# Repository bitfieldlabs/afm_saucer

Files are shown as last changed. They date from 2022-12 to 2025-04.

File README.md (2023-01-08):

# :flying_saucer: An RGB Attack from Mars Pinball Saucer PCB Replacement
As the title suggests this is drop in replacement for your Attack from Mars pinball saucer PCB. The large one.

No additional components or connections required!

As a bonus you get nice RGB colors!

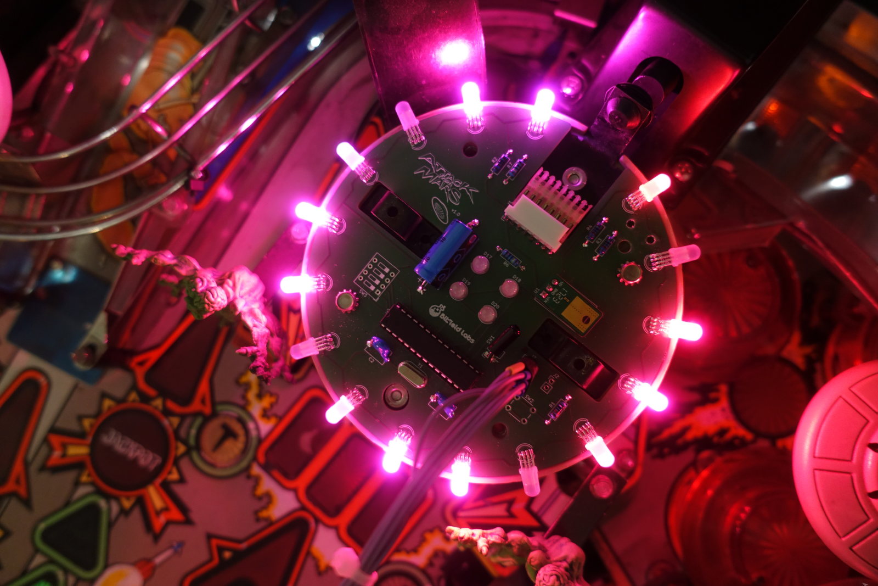
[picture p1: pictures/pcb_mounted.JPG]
mounted pcb


See a video of the saucer in action: https://vimeo.com/777834938

## :jigsaw: Required Components
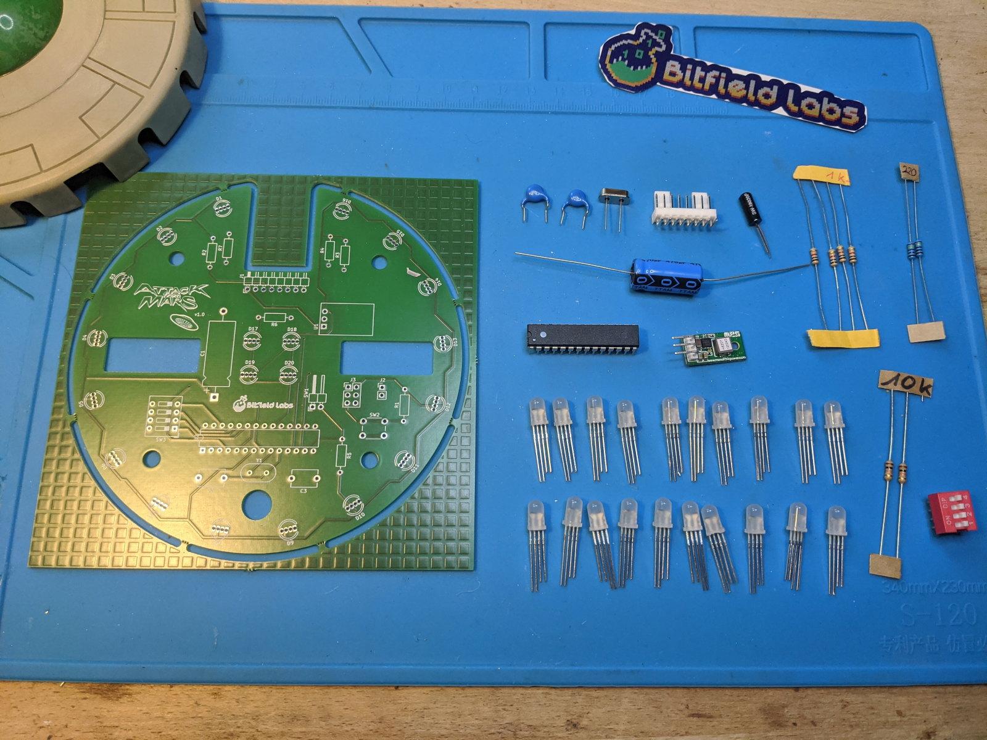
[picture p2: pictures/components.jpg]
components


The BOM is [here](https://github.com/bitfieldlabs/afm_saucer/blob/master/afm_saucer_pcb/afm_saucer/afm_saucer_bom.csv).
 
## :page_facing_up: Instructions
Some instructions can be found in the [doc folder](https://github.com/bitfieldlabs/afm_saucer/tree/master/doc).

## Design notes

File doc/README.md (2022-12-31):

## Assembly instructions
### Notes
It's easiest to start with the smalles (lowest profile) components and work the way up to the largest ones.

* *Note 1* Mind the polarity for the large capacitor C1!
* *Note 2* Mind the polarity for the Atmega chip U2!
* *Note 3* Mind the polarity for the LEDS! The flat side (-) is marked on the PCB. It's the connection with the square solder pad. It matches the LED's long legs.
* *Note 4* The legs of the 5V regulator (U1) must be bent straight in order to solder it flat to the PCB (see images). The VO (voltage out) pin must be connected to the upper solder pad, where U1 is marked. VI (voltage in) points toward the middle of the PCB.
* *Note 5* Remove pin 3 of the connector J1 as it is the key pin.
* *Note 6* Be careful not to short any LED pins, they are quite close to each other
* *Note 7* Switch 1 of the DIP switch SW3 points down to where SW3 is labelled

### Resistor values
The resistor values are
* R1: 10k
* R2, R3, R4, R5: 1k
* R6, R7: 220

### Assembly images
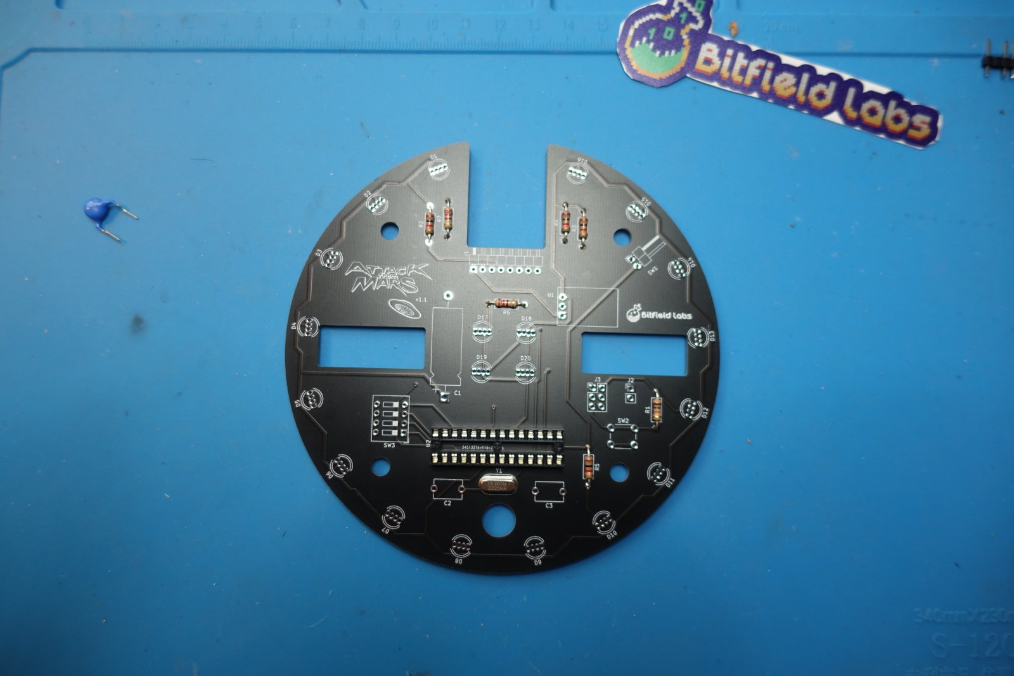
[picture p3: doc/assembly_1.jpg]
Assembly 1

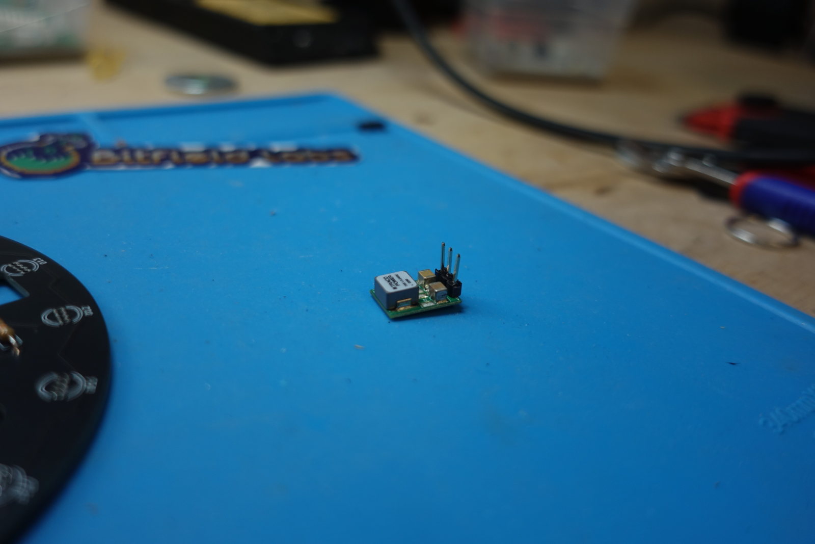
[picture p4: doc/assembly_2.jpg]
Assembly 1

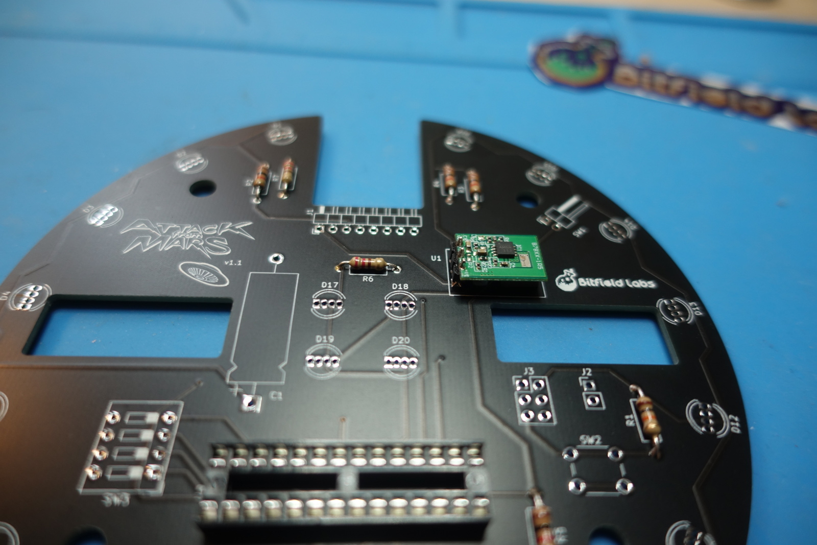
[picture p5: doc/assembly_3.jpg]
Assembly 1

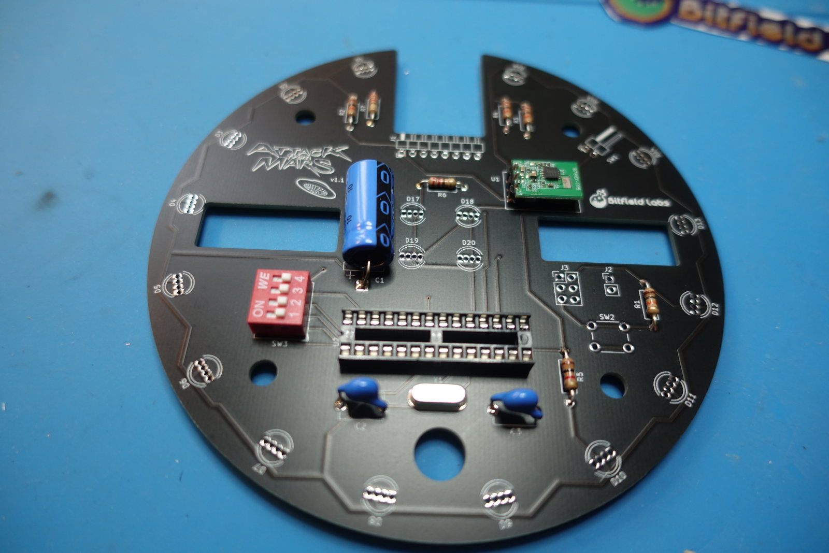
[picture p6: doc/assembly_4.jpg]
Assembly 1

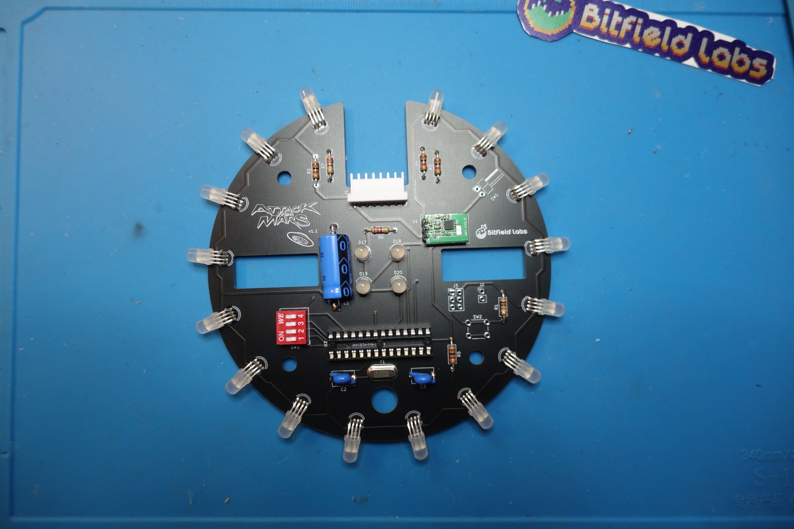
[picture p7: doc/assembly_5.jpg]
Assembly 1

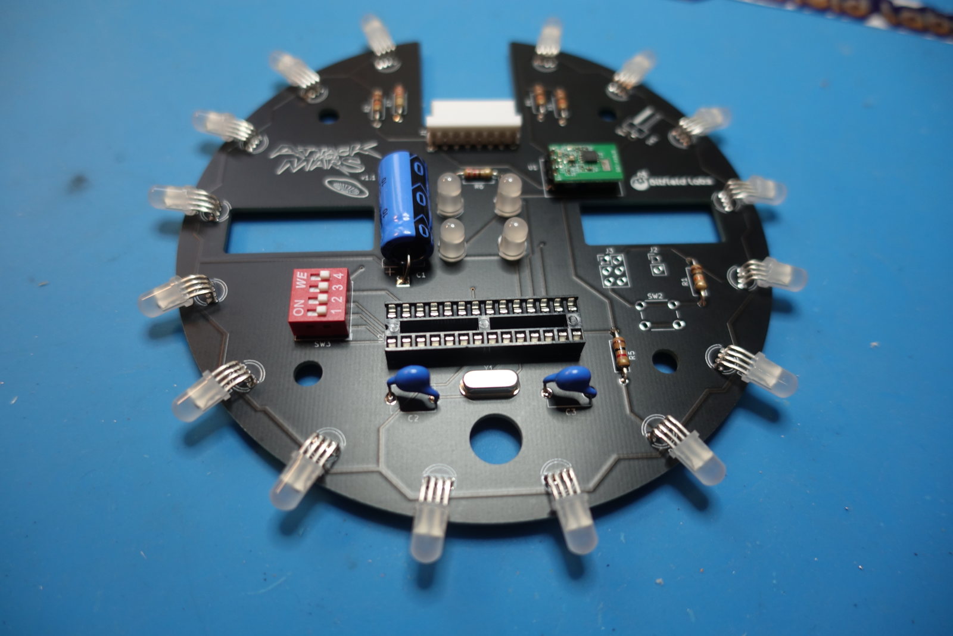
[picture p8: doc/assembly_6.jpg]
Assembly 1

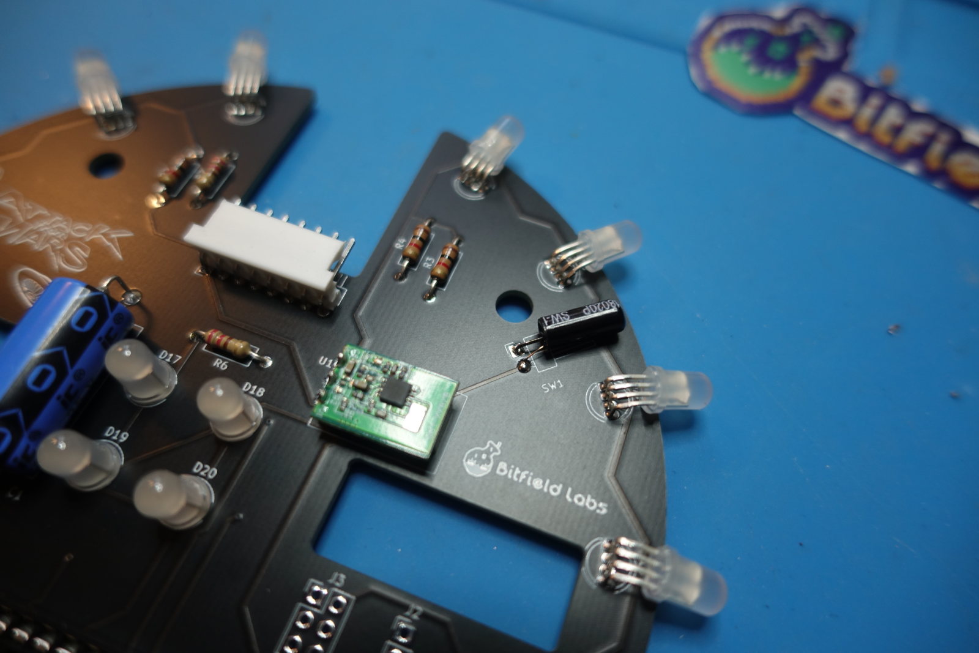
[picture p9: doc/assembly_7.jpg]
Assembly 1

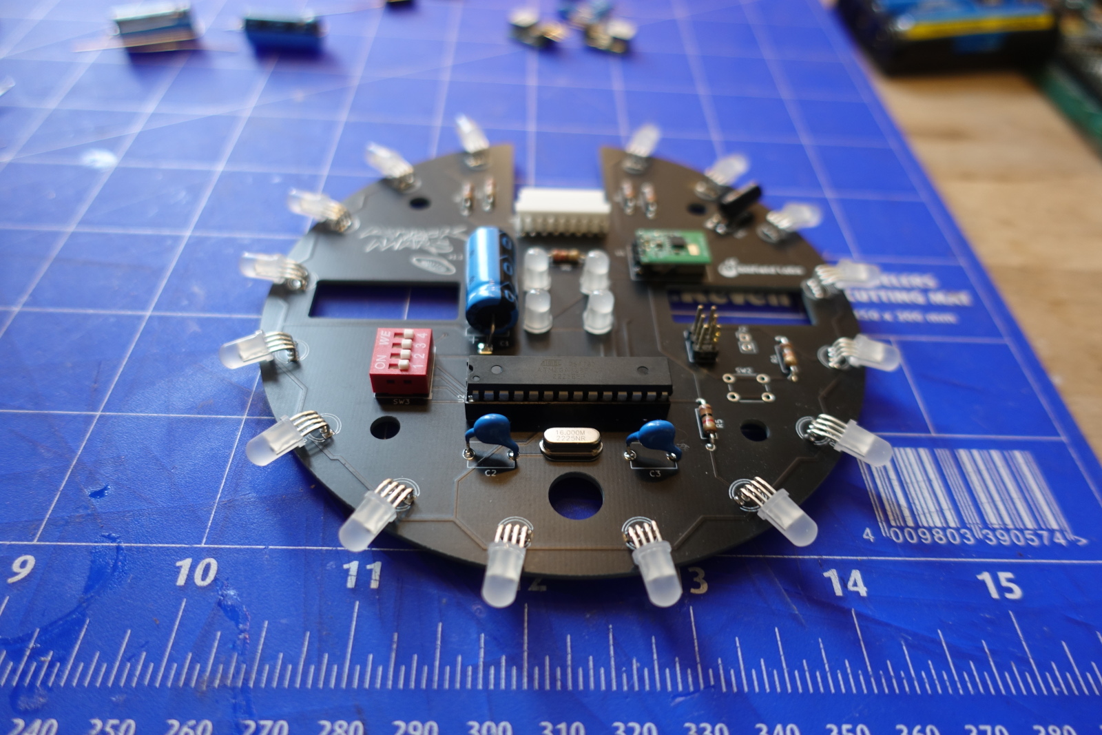
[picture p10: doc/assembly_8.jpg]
Assembly 1


## Programming the Atmega328p

### Fuses
The Atmega's fuses must be set to following values:
 * hfuse: 0xDA
 * efuse: 0xFD
 * lfuse: 0xFF

avrdude command:
```
avrdude -v -V -patmega328p -cavrisp -b19200 -P/dev/ttyUSB0 -D -F -Ulfuse:w:0xff:m -Uhfuse:w:0xda:m -Uefuse:w:0xfd:m
```

## Configuration
The different modes can be chosen using the four DIP switches.
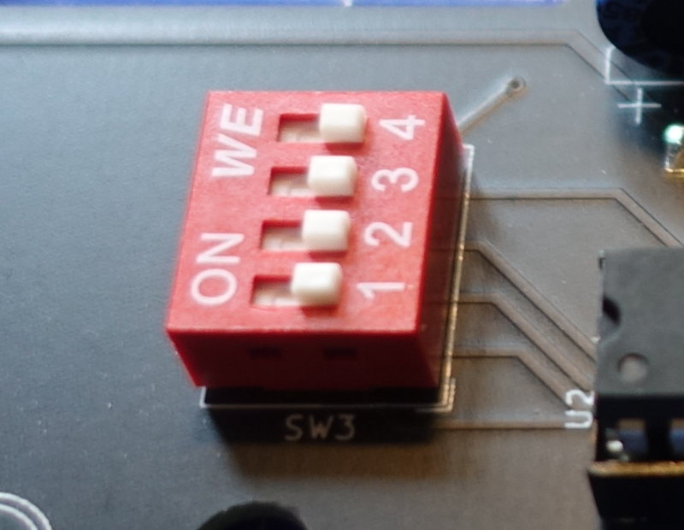
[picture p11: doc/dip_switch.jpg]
DIP Switch


. Switch Off / O Switch On

| Mode | Dip Switch 4321 | Description |
|-----:|---:|---|
| 0| ....| Random selection of mode 1-15 at each startup |
| 1| ...O| Teal background pulse. Red, orange and pink LEDs. |
| 2| ..O.| Rainbow background. Red, orange and light blue LEDs. |
| 3| ..OO| Yellow blinking background. Red, orange and light blue LEDs. |
| 4| .O..| Green breathing background. Red, orange and green LEDs. |
| 5| .O.O| No background, red LEDs. |
| 6| .OO.| Green breathing background. Red and green LEDs. |
| 7| .OOO| Red and green pulsing background. Red and blue LEDs. |
| 8| O...| Yellow and green breathing background. Red and blue LEDs. |
| 9| O..O| Alternating red and green background. Green and red LEDs. |
| 10| O.O.| No background. Rainbow LEDs. |
| 11| O.OO| No background. Red, green and ranbow LEDs. |
| 12| OO..| No background. Red, green and blue LEDs. |
| 13| OO.O| No background. Blue LEDs. |
| 14| OOO.| No background. Green LEDs. |
| 15| OOOO| Legacy mode. No fancy colors, just red LEDs. |

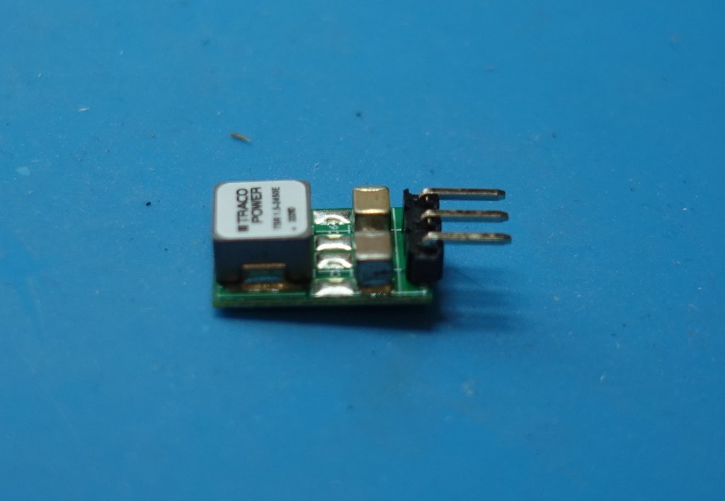
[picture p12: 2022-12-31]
doc/regulator_orig.jpg

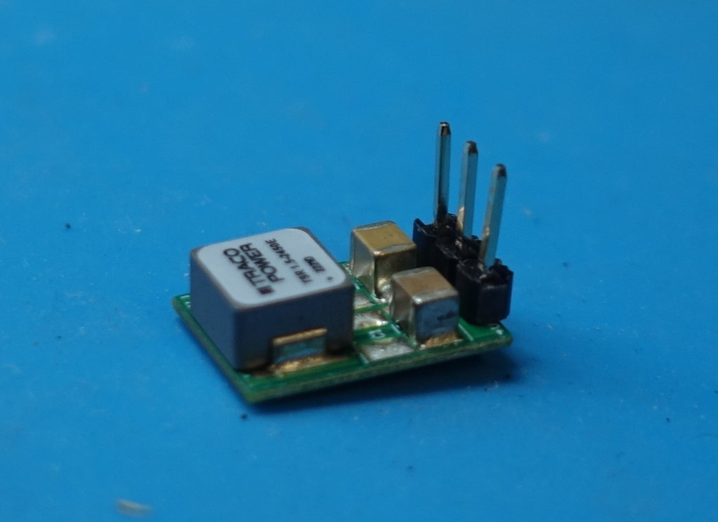
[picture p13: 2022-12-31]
doc/regulator_bent.jpg

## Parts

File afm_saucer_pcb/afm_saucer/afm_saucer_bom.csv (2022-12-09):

C1 | 100uF | Capacitor Axial L21.0mm D8.0mm P28.00mm | https://www.mouser.ch/ProductDetail/598-477TTA025M
C2, C3 | 22pF | Capacitor Disc D7.5mm W5.0mm P7.50mm | https://www.mouser.ch/ProductDetail/810-CC45SL3JD220JYNA
D1-D20 | APA-106-F5 | LED D5.0mm RGB | https://www.aliexpress.com/item/32945500333.html
J1 | Conn_01x08_Male | PinHeader 1x08 P2.54mm 90deg | https://www.mouser.ch/ProductDetail/538-22-05-7088
J2 | Conn_01x02_Male | PinHeader 1x02_P2.54mm Vertical
J3 | Conn_02x03_Odd_Even | PinHeader 2x03 P2.54mm Vertical
R1 | 10k | Resistor R_Axial L6.3mm D2.5mm P10.16mm
R2, R3, R4, R5 | 1k | Resistor R_Axial L6.3mm D2.5mm P10.16mm
R6, R7 | 220 | Resistor R_Axial L6.3mm D2.5mm P10.16mm
SW1 | Vibration Sensor | Vibration Sensor Medium/Fast | https://www.mouser.ch/ProductDetail/485-2384
SW2 | SW_Push | Push Button 6mm H9.5mm
SW3 | SW_DIP_x04 | DIP Switch x04 W7.62mm P2.54mm
U1 | OKI-78SR-5_1.5-W36-C | Converter DCDC_Murata OKI-78SR Horizontal | https://www.mouser.ch/ProductDetail/946-MEZD71202A-G
U2 | ATmega328P-P | DIP-28 W7.62mm
Y1 | Crystal | Crystal 2Pin W10.0mm H5.0mm | https://www.mouser.ch/ProductDetail/449-LFXTAL027945BULK

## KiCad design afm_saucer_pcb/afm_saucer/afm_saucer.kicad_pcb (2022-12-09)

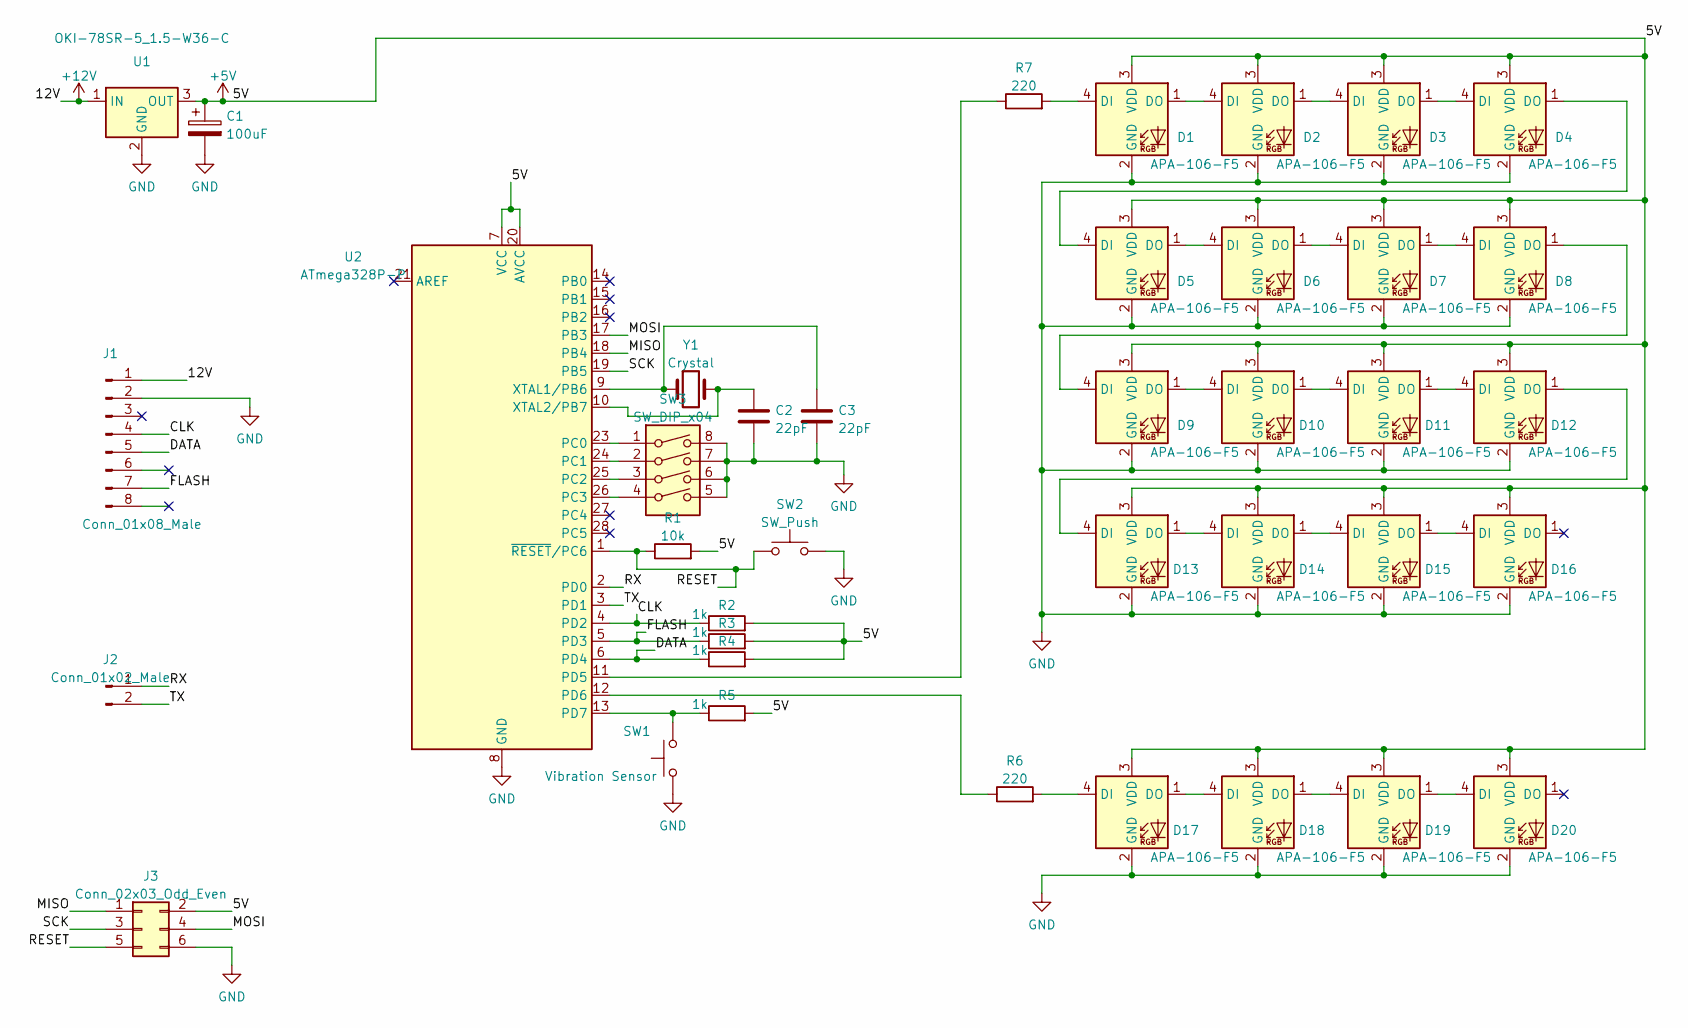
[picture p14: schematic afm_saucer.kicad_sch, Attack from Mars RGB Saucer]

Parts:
C1: 100uF; CP_Axial_L21.0mm_D8.0mm_P28.00mm_Horizontal
C2, C3: 22pF; C_Disc_D7.5mm_W5.0mm_P7.50mm
D1, D2, D3, D4, D5, D6, D7, D8, D9, D10, D11, D12, D13, D14, D15, D16, D17, D18, D19, D20: APA-106-F5; LED_D5.0mm-4_RGB
J1: Conn_01x08_Male; PinHeader_1x08_P2.54mm_Horizontal
J2: Conn_01x02_Male; PinHeader_1x02_P2.54mm_Vertical
J3: Conn_02x03_Odd_Even; PinHeader_2x03_P2.54mm_Vertical
R1: 10k; R_Axial_DIN0207_L6.3mm_D2.5mm_P10.16mm_Horizontal
R2, R3, R4, R5: 1k; R_Axial_DIN0207_L6.3mm_D2.5mm_P10.16mm_Horizontal
R6, R7: 220; R_Axial_DIN0207_L6.3mm_D2.5mm_P10.16mm_Horizontal
SW1: Vibration Sensor; PinHeader_1x02_P2.54mm_Horizontal
SW2: SW_Push; SW_PUSH_6mm_H9.5mm
SW3: SW_DIP_x04; SW_DIP_SPSTx04_Slide_9.78x12.34mm_W7.62mm_P2.54mm
U1: OKI-78SR-5_1.5-W36-C; Converter_DCDC_Murata_OKI-78SR_Horizontal
U2: ATmega328P-P; DIP-28_W7.62mm
Y1: Crystal; Resonator-2Pin_W10.0mm_H5.0mm

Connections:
+5V: C1.1, D1.3 (VDD), D2.3 (VDD), D3.3 (VDD), D4.3 (VDD), D5.3 (VDD), D6.3 (VDD), D7.3 (VDD), D8.3 (VDD), D9.3 (VDD), D10.3 (VDD), D11.3 (VDD), D12.3 (VDD), D13.3 (VDD), D14.3 (VDD), D15.3 (VDD), D16.3 (VDD), D17.3 (VDD), D18.3 (VDD), D19.3 (VDD), D20.3 (VDD), J3.2, R1.2, R2.2, R3.2, R4.2, R5.2, U1.3 (OUT), U2.7 (VCC), U2.20 (AVCC)
+12V: J1.1, U1.1 (IN)
/CLK: J1.4, R2.1, U2.4 (PD2)
/DATA: J1.5, R4.1, U2.6 (PD4)
/FLASH: J1.7, R3.1, U2.5 (PD3)
/MISO: J3.1, U2.18 (PB4)
/MOSI: J3.4, U2.17 (PB3)
/RESET: J3.5, R1.1, SW2.1, U2.1 (~RESET/PC6)
/RX: J2.1, U2.2 (PD0)
/SCK: J3.3, U2.19 (PB5)
/TX: J2.2, U2.3 (PD1)
GND: C1.2, C2.2, C3.2, D1.2 (GND), D2.2 (GND), D3.2 (GND), D4.2 (GND), D5.2 (GND), D6.2 (GND), D7.2 (GND), D8.2 (GND), D9.2 (GND), D10.2 (GND), D11.2 (GND), D12.2 (GND), D13.2 (GND), D14.2 (GND), D15.2 (GND), D16.2 (GND), D17.2 (GND), D18.2 (GND), D19.2 (GND), D20.2 (GND), J1.2, J3.6, SW1.1, SW2.2, SW3.5, SW3.6, SW3.7, SW3.8, U1.2 (GND), U2.8 (GND), U2.22 (GND)
unnamed: C2.1, U2.10 (XTAL2/PB7), Y1.2
unnamed: C3.1, U2.9 (XTAL1/PB6), Y1.1
unnamed: D1.1 (DO), D2.4 (DI)
unnamed: D1.4 (DI), R7.2
unnamed: D3.1 (DO), D4.4 (DI)
unnamed: D2.1 (DO), D3.4 (DI)
unnamed: D4.1 (DO), D5.4 (DI)
unnamed: D5.1 (DO), D6.4 (DI)
unnamed: D7.1 (DO), D8.4 (DI)
unnamed: D6.1 (DO), D7.4 (DI)
unnamed: D8.1 (DO), D9.4 (DI)
unnamed: D9.1 (DO), D10.4 (DI)
unnamed: D11.1 (DO), D12.4 (DI)
unnamed: D10.1 (DO), D11.4 (DI)
unnamed: D12.1 (DO), D13.4 (DI)
unnamed: D13.1 (DO), D14.4 (DI)
unnamed: D15.1 (DO), D16.4 (DI)
unnamed: D14.1 (DO), D15.4 (DI)
unnamed: D17.4 (DI), R6.2
unnamed: D18.1 (DO), D19.4 (DI)
unnamed: D17.1 (DO), D18.4 (DI)
unnamed: D19.1 (DO), D20.4 (DI)
unnamed: R5.1, SW1.2, U2.13 (PD7)
unnamed: R6.1, U2.12 (PD6)
unnamed: R7.1, U2.11 (PD5)
unnamed: SW3.1, U2.23 (PC0)
unnamed: SW3.2, U2.24 (PC1)
unnamed: SW3.3, U2.25 (PC2)
unnamed: SW3.4, U2.26 (PC3)

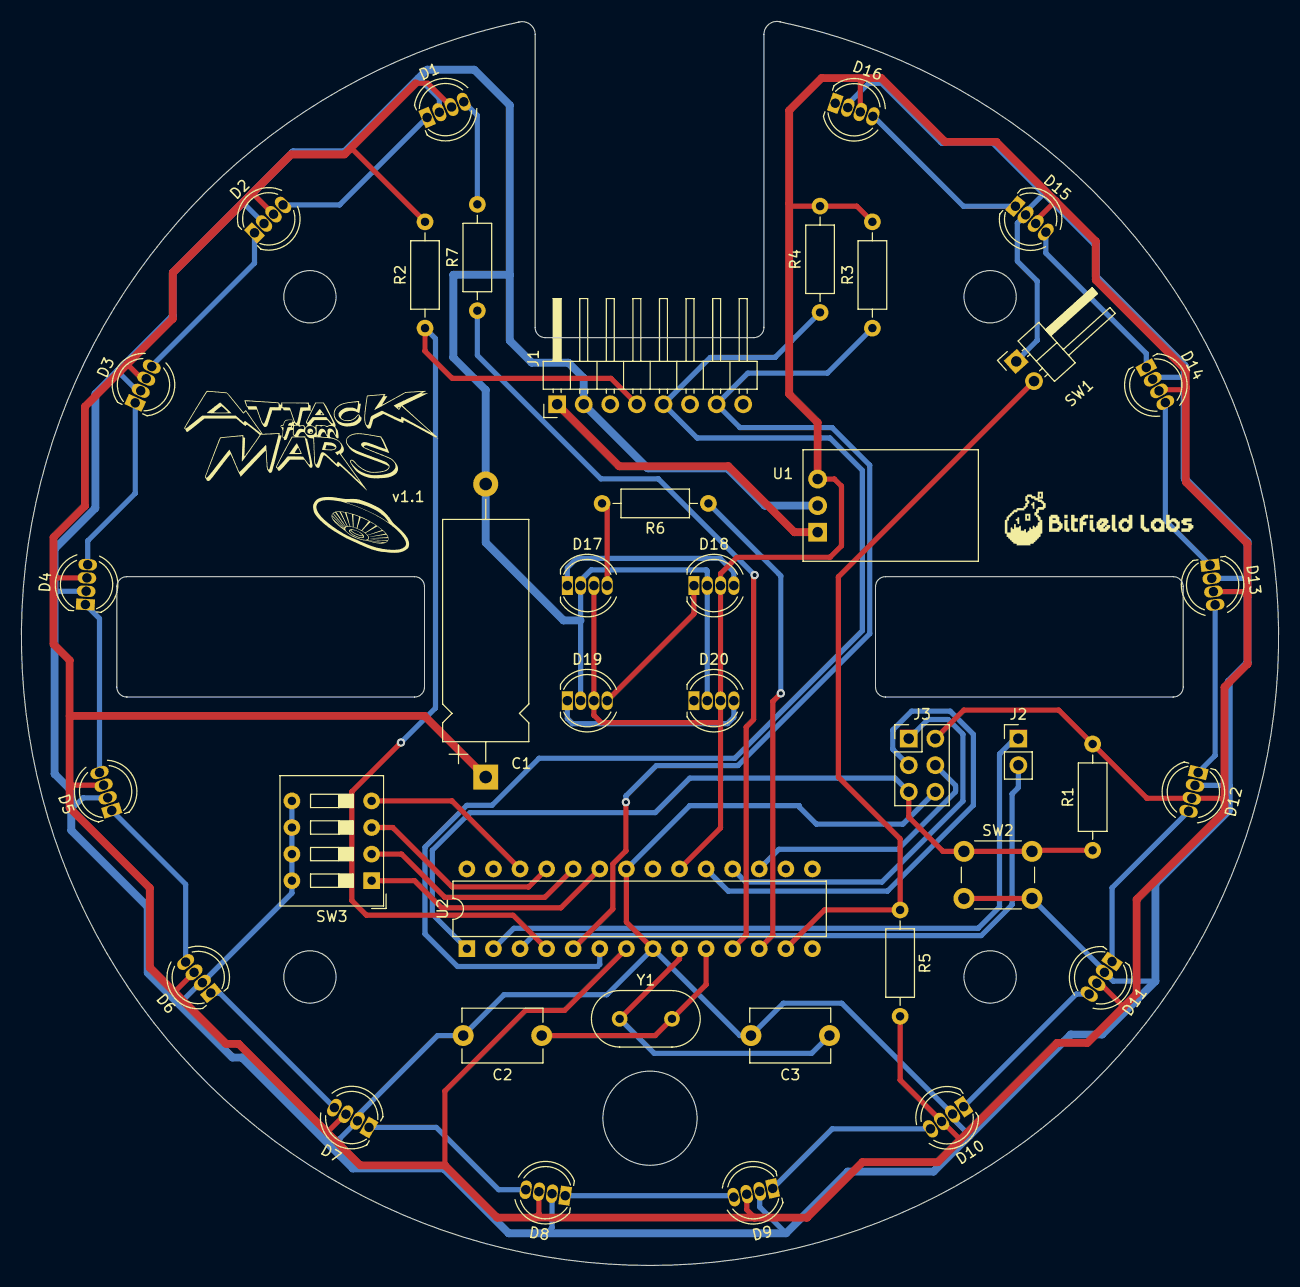
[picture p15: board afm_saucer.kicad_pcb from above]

Board: 2 copper layers, 120.1 x 118.9 mm, 40 parts (0 on the bottom side), 41 nets.

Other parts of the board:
QR: QRCODE; afm_logo_s

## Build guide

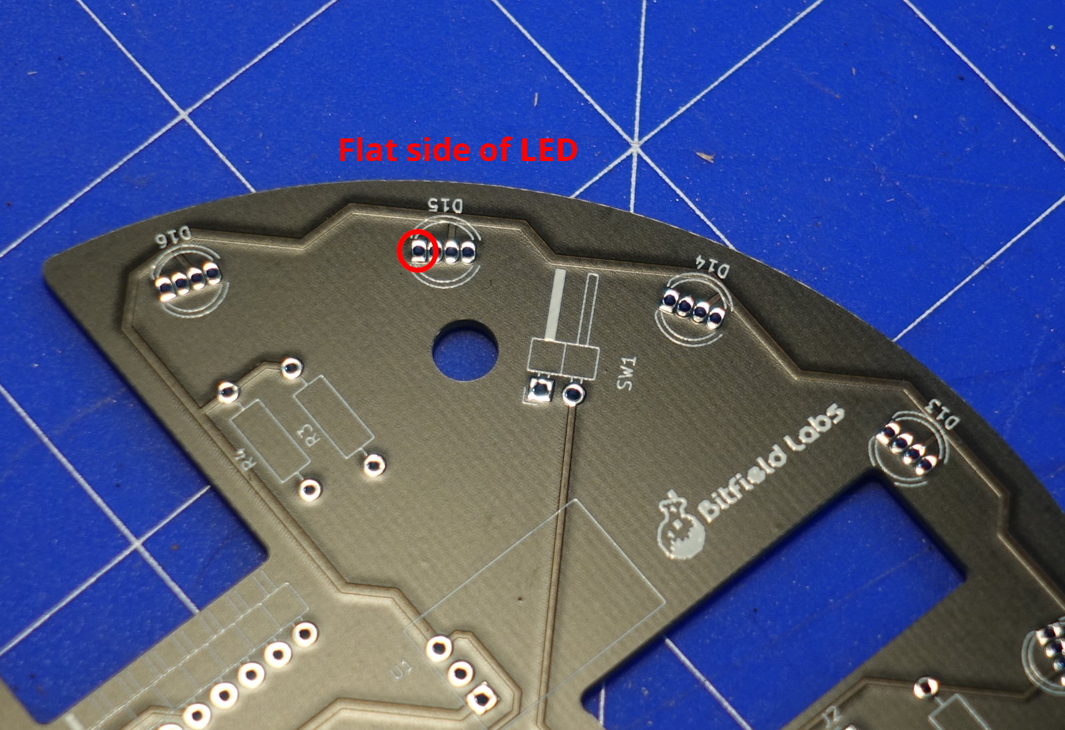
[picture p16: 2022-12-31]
doc/assembly_9.jpg

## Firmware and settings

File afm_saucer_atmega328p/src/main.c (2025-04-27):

/***********************************************************************
 *    _   _   _             _     __                                           
 *   /_\ | |_| |_ __ _  ___| | __/ _|_ __ ___  _ __ ___   /\/\   __ _ _ __ ___ 
 *  //_\\| __| __/ _` |/ __| |/ / |_| '__/ _ \| '_ ` _ \ /    \ / _` | '__/ __|
 * /  _  \ |_| || (_| | (__|   <|  _| | | (_) | | | | | / /\/\ \ (_| | |  \__ \
 * \_/ \_/\__|\__\__,_|\___|_|\_\_| |_|  \___/|_| |_| |_\/    \/\__,_|_|  |___/
 *
 *                              ____ ____ ___ 
 *                              |--< |__, |==]
 *
 *                      ____ ____ _  _ ____ ____ ____
 *                      ==== |--| |__| |___ |=== |--<
 *
 *  Copyright (c) 2022 bitfield labs
 * 
 ***********************************************************************
 *  This file is part of the Attack from Mars! RGB saucer project:
 *  https://github.com/bitfieldlabs/afm_saucer
 *
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
 *  You should have received a copy of the GNU Lesser General Public
 *  License along with afterglow.
 *  If not, see <http://www.gnu.org/licenses/>.
 ***********************************************************************/

#include <avr/io.h>
#include <avr/interrupt.h>
#include <avr/eeprom.h>
#include <util/delay.h>
#include <stdlib.h>
#include <stdbool.h>
#include "modes.h"


//------------------------------------------------------------------------------
// definitions

#define LED_UPDATE_INT 20                   // LED update interval [ms]
#define FLASH_CONS_CHECK 1                  // number of consecutive flash line checks in LED_UPDATE_INT interval required for flash triggering


//------------------------------------------------------------------------------
// global variables

static volatile uint16_t svLEDState = 0xffff;    // status for all 16 LEDs
static volatile bool svFlashState = false;       // flasher status
static volatile bool svShakerState = false;      // shaker status
static volatile uint16_t svFlashCounter = 0;     // consecutive passed flash line checks counter


//------------------------------------------------------------------------------
int main(void)
{
    // setup
    DDRD = 0b01100010;                      // all inputs except pins PD1, PD5, PD6
    DDRC = 0b00000000;                      // config DIPs on PC0-PC3
    PORTC |= 0b00001111;                    // enable DIP switch pullups
    EICRA |= (1 << ISC00) | (1 << ISC01);   // trigger INT0 on rising edge
    EIMSK |= (1 << INT0);                   // turn on INT0
    EICRA |= (1 << ISC11);                  // trigger INT1 on falling edge
    EIMSK |= (1 << INT1);                   // turn on INT1
    PCICR |= (1 << PCIE2);                  // enable pin interrupt
    PCMSK2 |= (1 << PCINT23);               // pin change interrupt on PD7 (PCINT23)

    // seed the random number generator
    uint32_t seed = eeprom_read_dword((uint32_t*)0);
    srand(seed);
    eeprom_write_dword((uint32_t*)0, rand());

    // enable interrupts
    sei();

    // to infinity and beyond
    while (true)
    {
        // update the LED state upon change
        updateLEDState(svLEDState);
        if (svFlashState)
        {
            // noise filtering: make sure the flash line is still kept low for at
            // least FLASH_CONS_CHECK consecutive checks
            if (!(PIND & 0b00001000))
            {
                svFlashCounter++;
                if (svFlashCounter >= FLASH_CONS_CHECK)
                {
                    triggerFlasher();
                    svFlashCounter = 0;
                    svFlashState = false;
                }
            }
            else
            {
                svFlashCounter = 0;
                svFlashState = false;
            }
        }
        if (svShakerState)
        {
            triggerShaker();
            svShakerState = false;
        }

        // update all LEDs
        updateLEDs();

        // wait a bit
        _delay_ms(LED_UPDATE_INT);
    }
    return 0;
}

//------------------------------------------------------------------------------
// LED data interrupt
ISR(INT0_vect)
{
    // shift new value into LED status
    svLEDState <<= 1;
    *((uint8_t*)&svLEDState) |= ((PIND >> 4) & 0x01);
}

//------------------------------------------------------------------------------
// flasher interrupt
ISR(INT1_vect)
{
    svFlashState = true;
}

//------------------------------------------------------------------------------
// shaker interrupt
ISR(PCINT2_vect)
{
    svShakerState = true;
}

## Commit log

2022-12-09 Added BOM
    [afm_saucer_bom.csv]
2022-12-09 PCB v1.1
    [afm_saucer-B_Cu.gbr, afm_saucer-B_Mask.gbr, afm_saucer-B_Paste.gbr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]
2025-04-27 Flasher interrupt noise filtering
    [main.c]

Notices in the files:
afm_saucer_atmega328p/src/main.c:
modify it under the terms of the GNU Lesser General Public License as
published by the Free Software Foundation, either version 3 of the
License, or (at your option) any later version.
